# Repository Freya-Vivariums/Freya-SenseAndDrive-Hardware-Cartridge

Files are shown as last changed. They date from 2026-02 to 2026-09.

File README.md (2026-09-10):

Freya banner

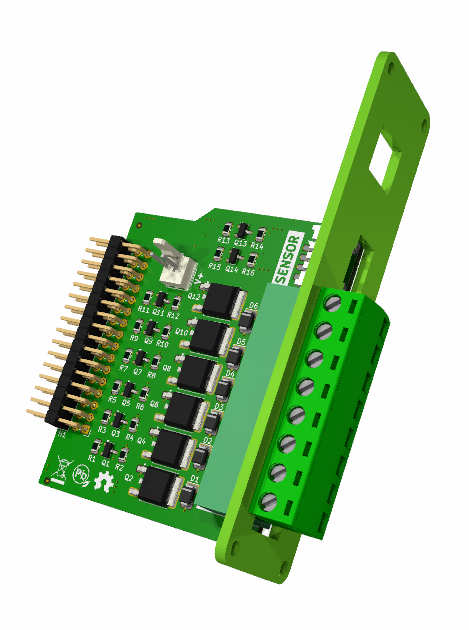
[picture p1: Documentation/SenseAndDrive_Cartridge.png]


The **Sense'n'Drive Hardware Cartridge** equips the [Edgeberry™](https://edgeberry.github.io) based controller with the capability for connecting sensors and driving actuators.

**Features**
- **6 digital outputs** for driving actuators directly or with interposing relays, with internal or external power source.
- **An I²C port** level-shifted to 5V for reliably connecting to the [Freya "Terra" Sensor](https://github.com/Freya-Vivariums/Freya-Terra-Sensor)

<br clear="right"/>

## Usage

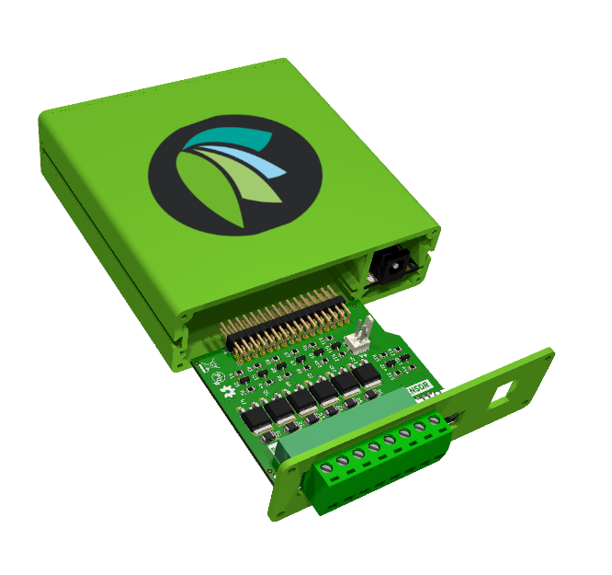
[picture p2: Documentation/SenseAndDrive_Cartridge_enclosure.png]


The Sense'n'Drive Hardware Cartridge is slided in into the expansion slot on the back side of the controller. For using it in your application, install the driver from this repository and include the sdk library in your software.

```js
const { SenseNDriveClient } = require('@freya-vivariums/freya-hardware-cartridge');

const cartridge = new SenseNDriveClient();

cartridge.on('ready', async () => {
  await cartridge.setOutput({ channel: 1, config: { mode: 'switch' }, setpoint: 1 });
  setTimeout(() => cartridge.setOutput({ channel: 1, setpoint: 0 }), 1000);
});
```

<br clear="left"/>

## Hardware

### Sensor Port
The I²C sensor port is **level-shifted to 5V**, and wired to the `HY2.0-4P` connector (informally known as the _Grove connector_) in the following way - making it directly compatible with a wide range of I²C breakout boards from a variety of ecosystems.

|  Pin | Function |
|---|---|
| 1 | SCL |
| 2 | SDA |
| 3 | +5V |
| 4 | GND |

> [!NOTE]
> Before you can use the I²C port `/dev/i2c-1` on Raspberry Pi, it must be enabled by running`sudo raspi-config nonint do_i2c 0`. Or by configuring the overlay manually.

### Digital Outputs
The digital outputs are **sourcing MOSFET** channels rated for up to 1A each, suitable for driving standard industrial actuators such as relays, contactors and solenoids. Output voltage follows the externally applied supply. At 24V DC, the outputs conform to the conventional sourcing digital output arrangement described in IEC 61131-2, so any actuator designed for a standard PLC output can be connected directly. Built-in flyback diodes clamp inductive loads.

> [!IMPORTANT]
> **The digital outputs do not feature internal short-circuit or overcurrent protection**. It is recommended to install a 1A or 1.25A fast-acting fuse on the power supply line.

> [!WARNING]
> The hardware cartridge is designed with a **shared ground for all voltages (non-isolated)**. Always ensure the power supply for the digital outputs and the power supply for the device share a common ground.

The Raspberry Pi GPIO pins are connected to the digital outputs as following:

|Channel |  GPIO  | Software Driver Channel | Comment |
|---|---|---|---|
| D1 | GPIO21 | 1 | |
| D2 | GPIO20 | 2 | |
| D3 | GPIO16 | 3 | |
| D4 | GPIO13 | 4 | |
| D5 | GPIO12 | 5 |Hardware PWM capable* |
| D6 | GPIO18 | 6 |Hardware PWM capable* |

> [!NOTE]
> TODO a note on Hardware PWM on Raspberry Pi

> [!NOTE]
> Controling the digital outputs can be done directly from the commandline using `pinctrl`. For example `pinctrl set 21 op dh` to use GPIO21 as a digital output and set high.

## Software
The **Sense'n'Drive Hardware Cartridge driver** included in the repository is a systemd service (`freya.cartridge.sensendrive`) that is interacted with via a D-Bus API by the client libraries. The service provides methods for controlling the digital outputs in several operating modes.

### D-Bus API
System bus service and interface `freya.cartridge.sensendrive`. Methods are `(s) → s`: a bare JSON request in,
an enveloped JSON response out.

| Method | Request | Result |
|---|---|---|
| `GetOutputs` | `{}` | `{ "outputs": [ ...6...] }` |
| `SetOutput` | one write document | the resulting state |
| `SetOutputs` | `{ "outputs": [ ... ] }` | array of states |

#### Example
`SetOutput` request argument string:
```json
{
  "channel": 2,
  "config": { "mode": "pulse", "frequency_hz": 0.1, "rampRate": 0 },
  "setpoint": 0.321
}
```
Response string:
```json
{ "ok": false, "error": { "code": "EINVAL", "message": "..." } }
```
Or
```json
{ "ok": true, "result": {
    "channel": 2,
    "config": { "mode": "pulse", "frequency_hz": 0.1, "rampRate": 0 },
    "setpoint": 0.321,
    "actual": 0.3 } }
```

Signals: `Ready` at startup, and `OutputChanged` carrying one state document
whenever a channel changes.

## License & Collaboration
**Copyright© 2024-2026 Sanne 'SpuQ' Santens**. The hardware and enclosure are released under the [**CERN OHL-W**](Hardware/LICENSE.txt) license. The driver is released under the [**GNU GPL-3.0**](Software/Driver/LICENSE.txt) license and the sdk libraries under the [**MIT license**](Software/Client/LICENSE.txt) Trademark rules apply to the [Freya™ brand](https://github.com/Freya-Vivariums/.github/blob/main/brand/Freya_Trademark_Rules_and_Guidelines.md).

### Collaboration

If you'd like to contribute to this project, please follow these guidelines:
1. Fork the repository and create your branch from `main`.
2. Make your changes and ensure they adhere to the project's design style and conventions.
3. Test your changes thoroughly.
4. Ensure your commits are descriptive and well-documented.
5. Open a pull request, describing the changes you've made and the problem or feature they address.

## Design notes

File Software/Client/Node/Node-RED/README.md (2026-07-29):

Freya Banner



**[Node-RED](https://nodered.org/)** is a visual programming tool that lets you wire together hardware, APIs, and online services by connecting blocks in a flow-based editor. The **Freya Hardware Cartridge** Node-RED node lets you control the digital outputs of the Freya SenseAndDrive Hardware Cartridge directly from your Node-RED flows over D-Bus.

<br clear="right"/>



## Installation
#### Node-RED flow editor
Navigate to `Settings > Manage Palette`, then in the `Install` tab, search for `@freya-vivariums/freya-hardware-cartridge-node-red-contrib` and click the `Install` button.

#### Manually using NPM
On your device, navigate to the Node-RED folder (on a Freya system, it's at `/opt/Freya/nodered`), and run:
```
npm install @freya-vivariums/freya-hardware-cartridge-node-red-contrib
```

## Node: Digital Output
Controls one of the 6 outputs of the Hardware Cartridge. All Digital Output
nodes automatically share a single connection to the `freya.cartridge.sensendrive`
system D-Bus service, so no separate configuration node is needed. Configure the
physical output channel (1–6) and the mode.

**Input** (`msg.payload`):
- a number `0.0`–`1.0` sets the channel setpoint;
- a boolean maps to a setpoint of `0` / `1`;
- a partial write object `{ config, setpoint }` for full control.

**Output:** a message whose `payload` is the channel state document, emitted
whenever the channel's realized state changes.

**Modes:**
- **Off** (`off`) — output driven low.
- **On/Off** (`switch`) — output high when the realized value is ≥ 0.5.
- **Pulse** (`pwm-slow`) — slow pulse-width modulation, **0.001–1 Hz**. Duty
  cycle equals the setpoint (e.g. 0.1 Hz at 0.3 → 3 s on / 7 s off every 10 s).
- **PWM** (`pwm`) — pulse-width modulation, **1–60 Hz**. The 60 Hz ceiling is
  bounded by the `pinctrl` process-spawn rate (one process per edge, ~1.6 ms
  median / ~7 ms worst on a Raspberry Pi 5); duty accuracy softens toward the
  top of the range. ("PWM fast" is reserved for a future tier.)

  The frequency cap is not the only limit: because each edge costs a process
  spawn, the shortest resolvable on-time is **~5 ms**, and at low duty that
  minimum binds before the frequency does. 60 Hz is fine at 50 % duty (~8 ms
  on-time) but not at 5 % (~0.8 ms). This is not enforced — extreme
  duty/frequency pairs simply degrade gracefully rather than being rejected.

**Frequency** is required for the two PWM modes and rejected out of range; it is
ignored (and hidden) for Off / On/Off. **Ramp rate** is a soft start/stop in
setpoint units per second (`0` = instant); it slides the realized value toward
the setpoint, delaying the On/Off threshold crossing or the PWM duty change.

**Ramping applies in every mode except `off`.** Selecting **Off** is a hard,
immediate stop — it snaps the output low regardless of ramp rate. To fade an
output down instead, keep its mode and set the setpoint to `0`: **`setpoint: 0`
fades, `mode: off` snaps.**

## License & Collaboration
**Copyright© 2025 Sanne 'SpuQ' Santens**. This project is licensed under the **[MIT License](LICENSE.txt)**. The [Rules & Guidelines](https://github.com/Freya-Vivariums/.github/blob/main/brand/Freya_Trademark_Rules_and_Guidelines.md) apply to the usage of the Freya Vivariums™ brand.

### Collaboration
If you'd like to contribute to this project, please follow these guidelines:
1. Fork the repository and create your branch from `main`.
2. Make your changes and ensure they adhere to the project's coding style and conventions.
3. Test your changes thoroughly.
4. Ensure your commits are descriptive and well-documented.
5. Open a pull request, describing the changes you've made and the problem or feature they address.

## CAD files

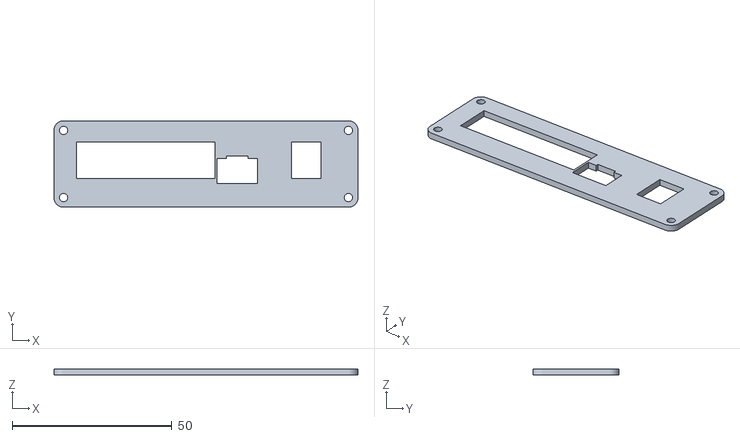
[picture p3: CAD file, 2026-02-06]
Documentation/Edgeberry_SenseAndDrive_faceplate.stl
95.0 x 27.0 x 2.00

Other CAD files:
Enclosure/Edgeberry_SenseAndDrive_faceplate.FCStd

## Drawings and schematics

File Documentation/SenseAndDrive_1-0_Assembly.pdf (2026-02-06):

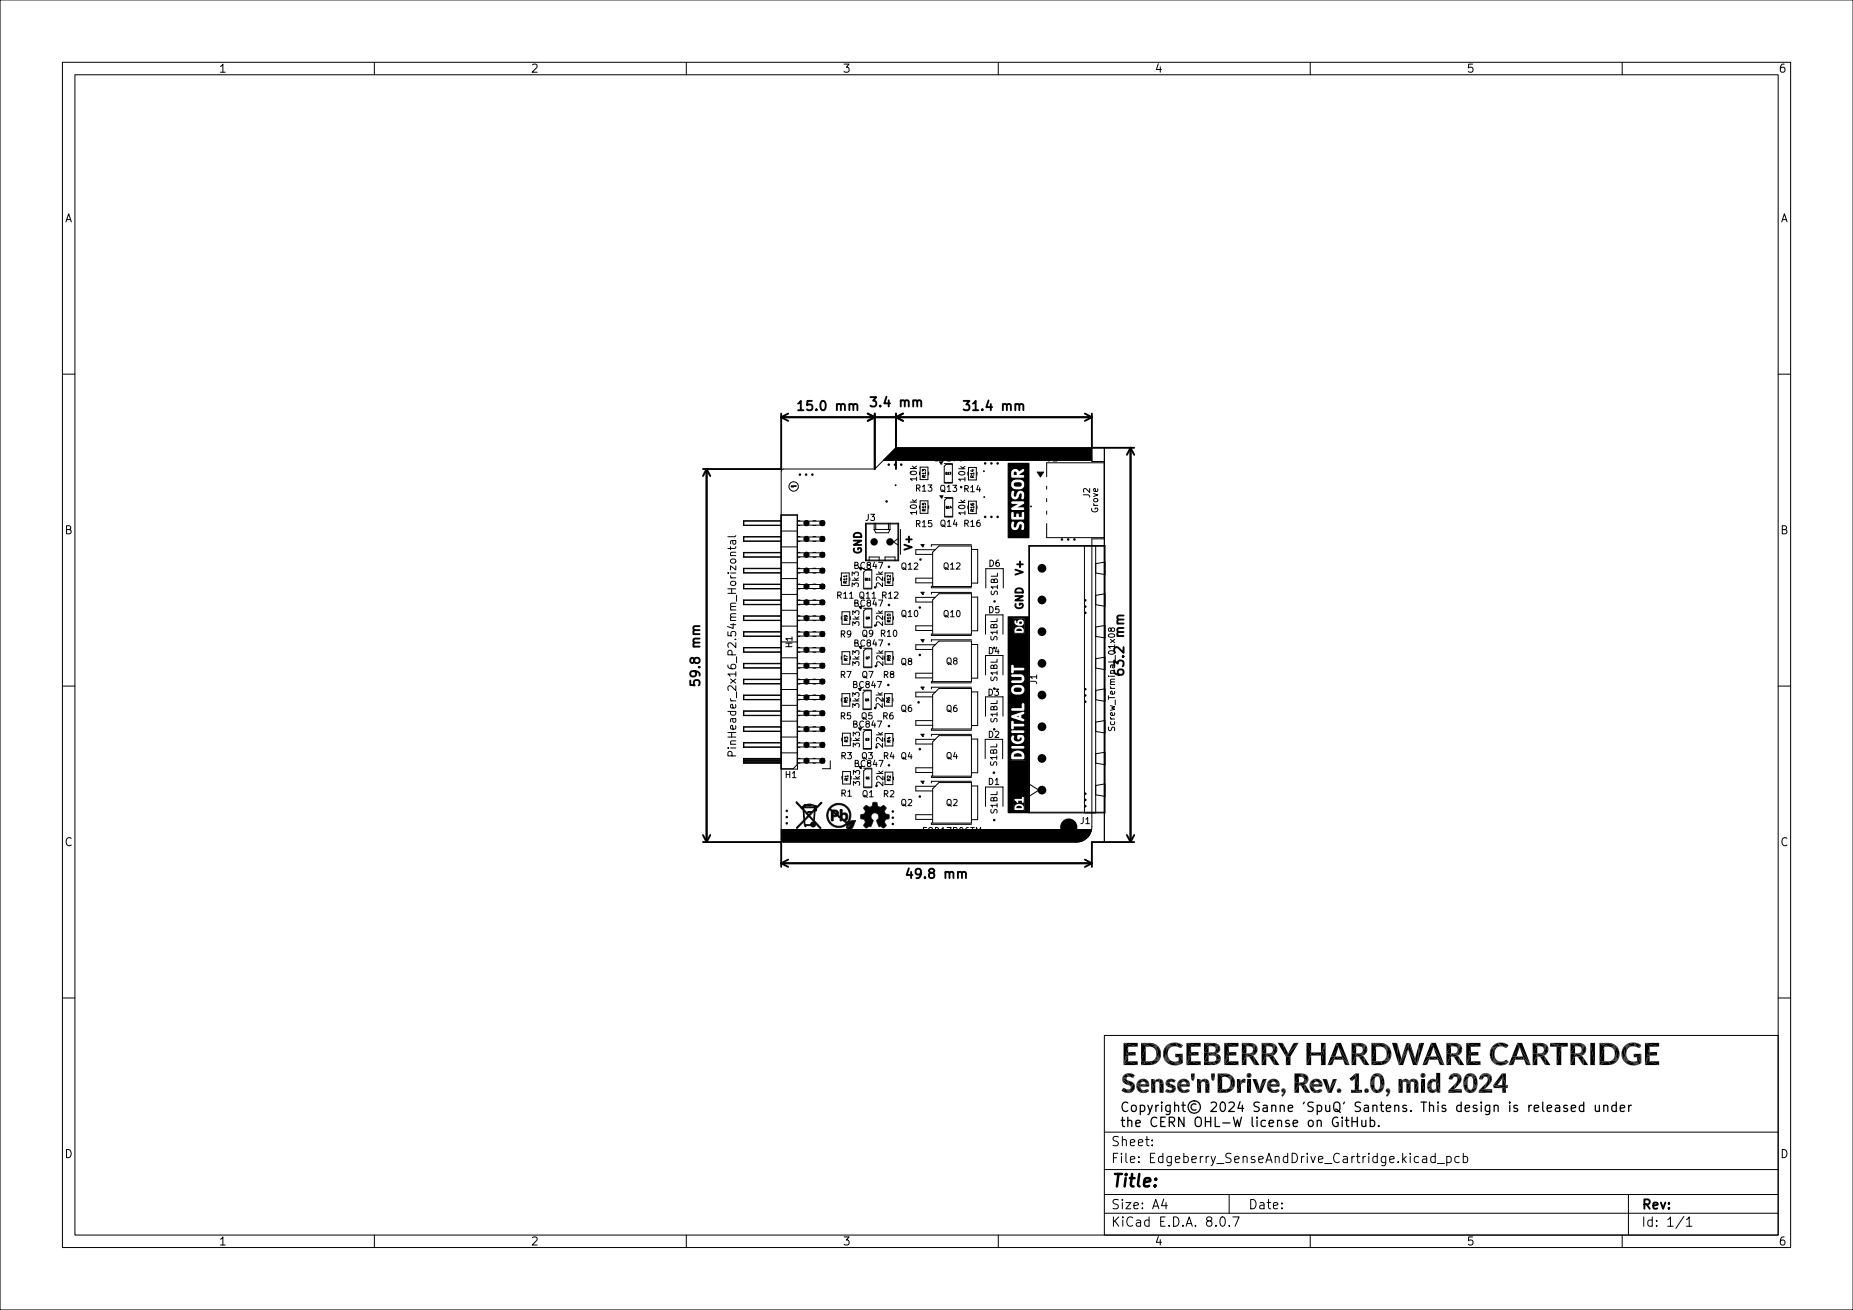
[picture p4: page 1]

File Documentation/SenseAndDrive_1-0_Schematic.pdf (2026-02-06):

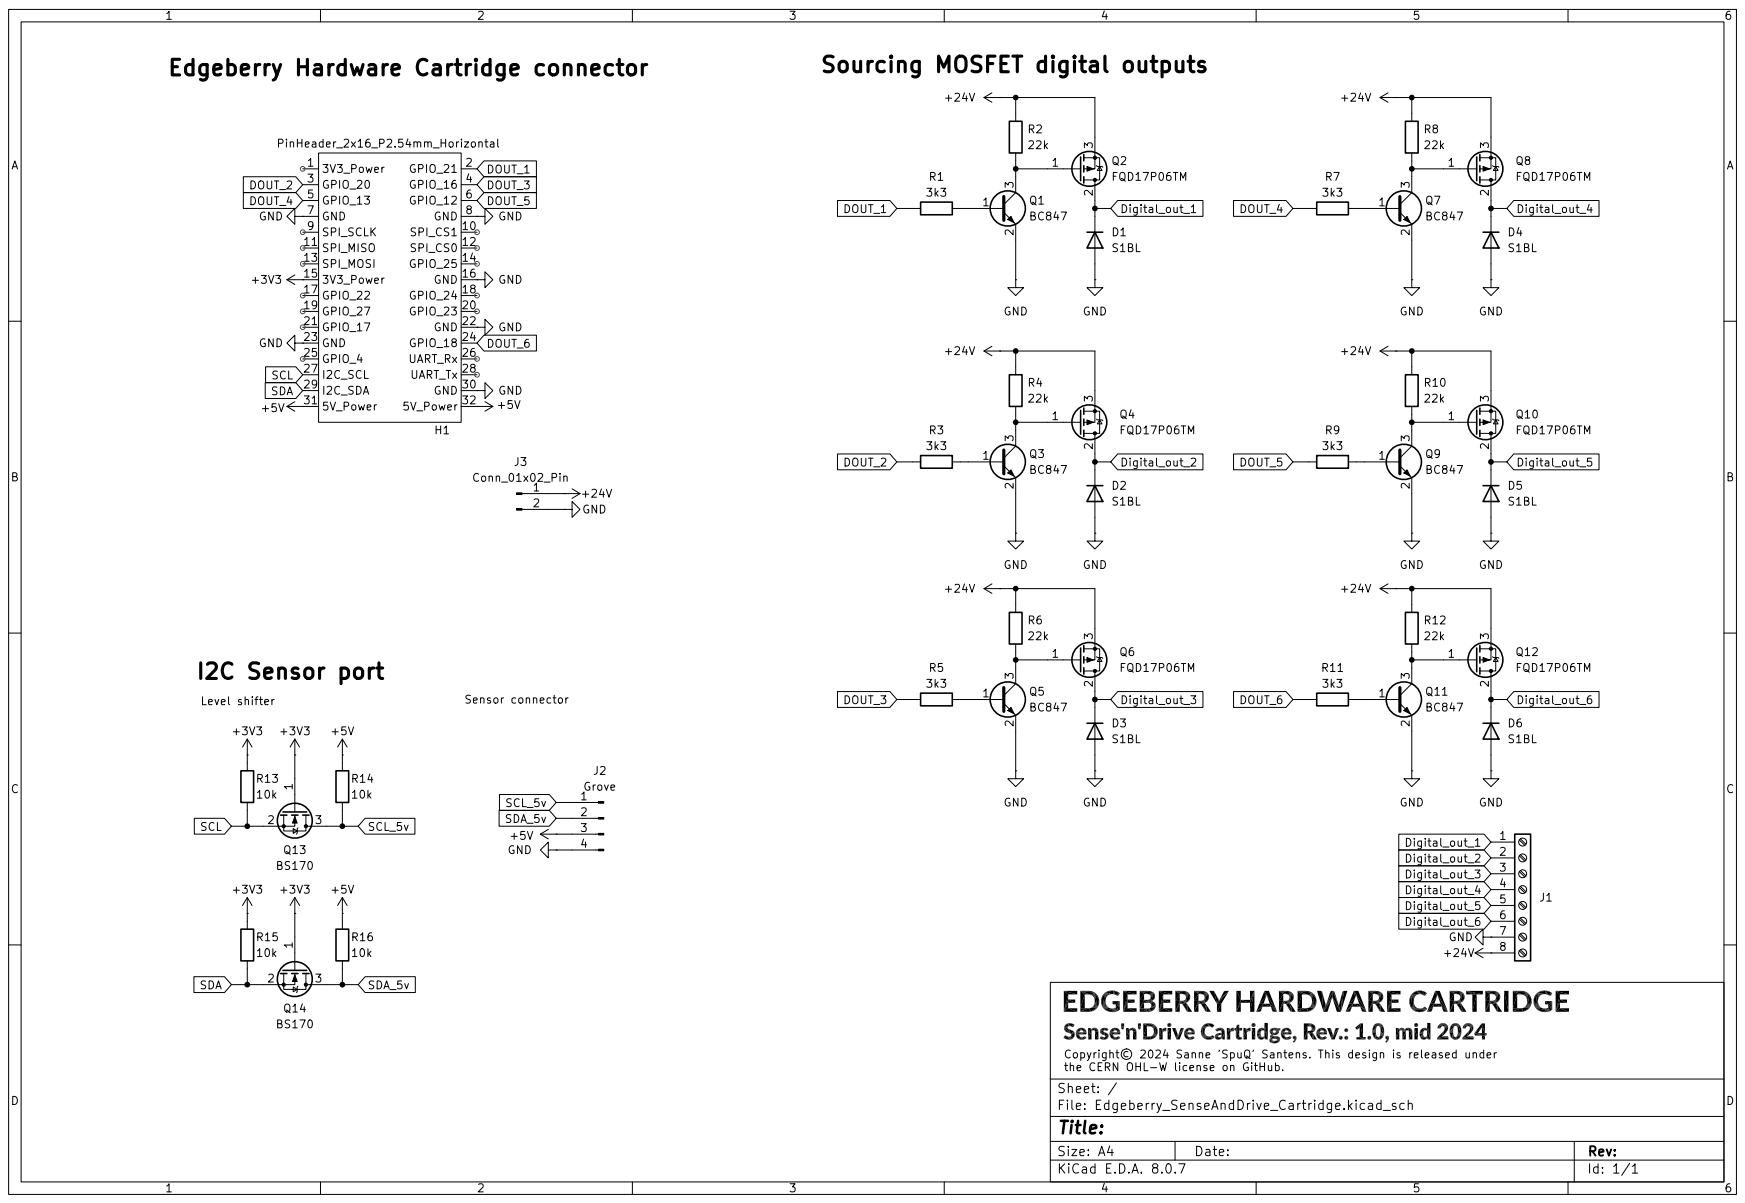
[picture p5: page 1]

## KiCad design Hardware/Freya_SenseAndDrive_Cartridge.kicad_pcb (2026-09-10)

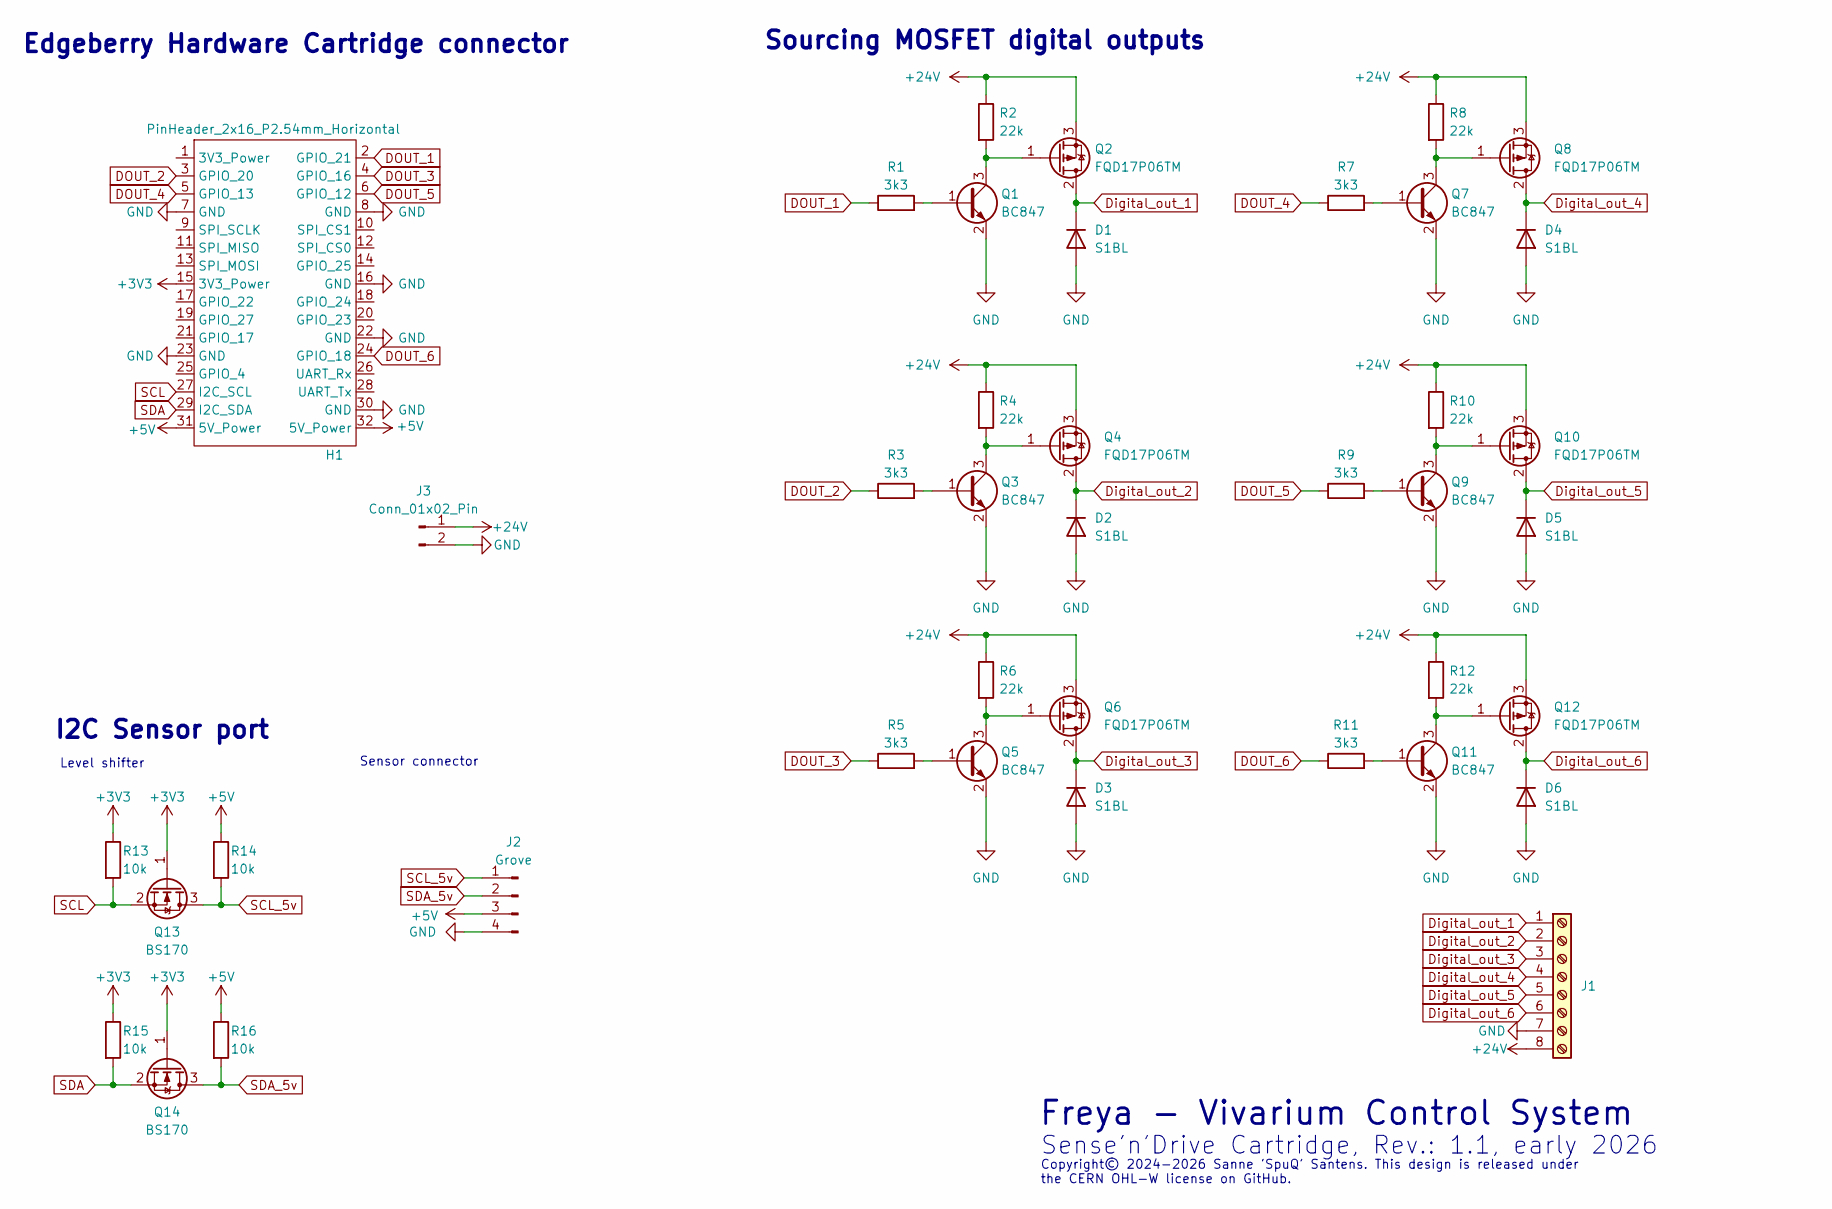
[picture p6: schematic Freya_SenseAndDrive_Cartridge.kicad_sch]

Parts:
D1, D2, D3, D4, D5, D6: S1BL; S1BL_diode
H1: PinHeader_2x16_P2.54mm_Horizontal
J1: Screw_Terminal_01x08; PhoenixContact_MSTBA_2,5_8-G-5,08_1x08_P5.08mm_Horizontal
J2: Grove; Grove_SMD_right_angle
J3: Conn_01x02_Pin; Molex_KK-254_AE-6410-02A_1x02_P2.54mm_Vertical
Q1, Q3, Q5, Q7, Q9, Q11: BC847; SOT-23
Q2, Q4, Q6, Q8, Q10, Q12: FQD17P06TM; TO-252-2
Q13, Q14: BS170; SOT-23
R1, R3, R5, R7, R9, R11: 3k3; R_0805_2012Metric
R2, R4, R6, R8, R10, R12: 22k; R_0805_2012Metric
R13, R14, R15, R16: 10k; R_0805_2012Metric

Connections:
+3V3: H1.15 (3V3_Power), Q13.1 (G), Q14.1 (G), R13.1, R15.1
+5V: H1.31 (5V_Power), H1.32 (5V_Power), J2.3, R14.1, R16.1
+24V: J1.8, J3.1, Q2.3 (S), Q4.3 (S), Q6.3 (S), Q8.3 (S), Q10.3 (S), Q12.3 (S), R2.1, R4.1, R6.1, R8.1, R10.1, R12.1
DOUT_1: H1.2 (GPIO_21), R1.1
DOUT_2: H1.3 (GPIO_20), R3.1
DOUT_3: H1.4 (GPIO_16), R5.1
DOUT_4: H1.5 (GPIO_13), R7.1
DOUT_5: H1.6 (GPIO_12), R9.1
DOUT_6: H1.24 (GPIO_18), R11.1
Digital_out_1: D1.1 (K), J1.1, Q2.2 (D)
Digital_out_2: D2.1 (K), J1.2, Q4.2 (D)
Digital_out_3: D3.1 (K), J1.3, Q6.2 (D)
Digital_out_4: D4.1 (K), J1.4, Q8.2 (D)
Digital_out_5: D5.1 (K), J1.5, Q10.2 (D)
Digital_out_6: D6.1 (K), J1.6, Q12.2 (D)
GND: D1.2 (A), D2.2 (A), D3.2 (A), D4.2 (A), D5.2 (A), D6.2 (A), H1.7 (GND), H1.8 (GND), H1.16 (GND), H1.22 (GND), H1.23 (GND), H1.30 (GND), J1.7, J2.4, J3.2, Q1.2 (E), Q3.2 (E), Q5.2 (E), Q7.2 (E), Q9.2 (E), Q11.2 (E)
unnamed: Q1.1 (B), R1.2
unnamed: Q1.3 (C), Q2.1 (G), R2.2
unnamed: Q3.1 (B), R3.2
unnamed: Q3.3 (C), Q4.1 (G), R4.2
unnamed: Q5.1 (B), R5.2
unnamed: Q5.3 (C), Q6.1 (G), R6.2
unnamed: Q7.1 (B), R7.2
unnamed: Q7.3 (C), Q8.1 (G), R8.2
unnamed: Q9.1 (B), R9.2
unnamed: Q9.3 (C), Q10.1 (G), R10.2
unnamed: Q11.1 (B), R11.2
unnamed: Q11.3 (C), Q12.1 (G), R12.2
SCL: H1.27 (I2C_SCL), Q13.2 (S), R13.2
SCL_5v: J2.1, Q13.3 (D), R14.2
SDA: H1.29 (I2C_SDA), Q14.2 (S), R15.2
SDA_5v: J2.2, Q14.3 (D), R16.2

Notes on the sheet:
Copyright© 2024-2026 Sanne 'SpuQ' Santens. This design is released under the CERN OHL-W license on GitHub.
I2C Sensor port
Freya - Vivarium Control System
Sense'n'Drive Cartridge, Rev.: 1.1, early 2026
Sourcing MOSFET digital outputs
Sensor connector
Level shifter
Edgeberry Hardware Cartridge connector

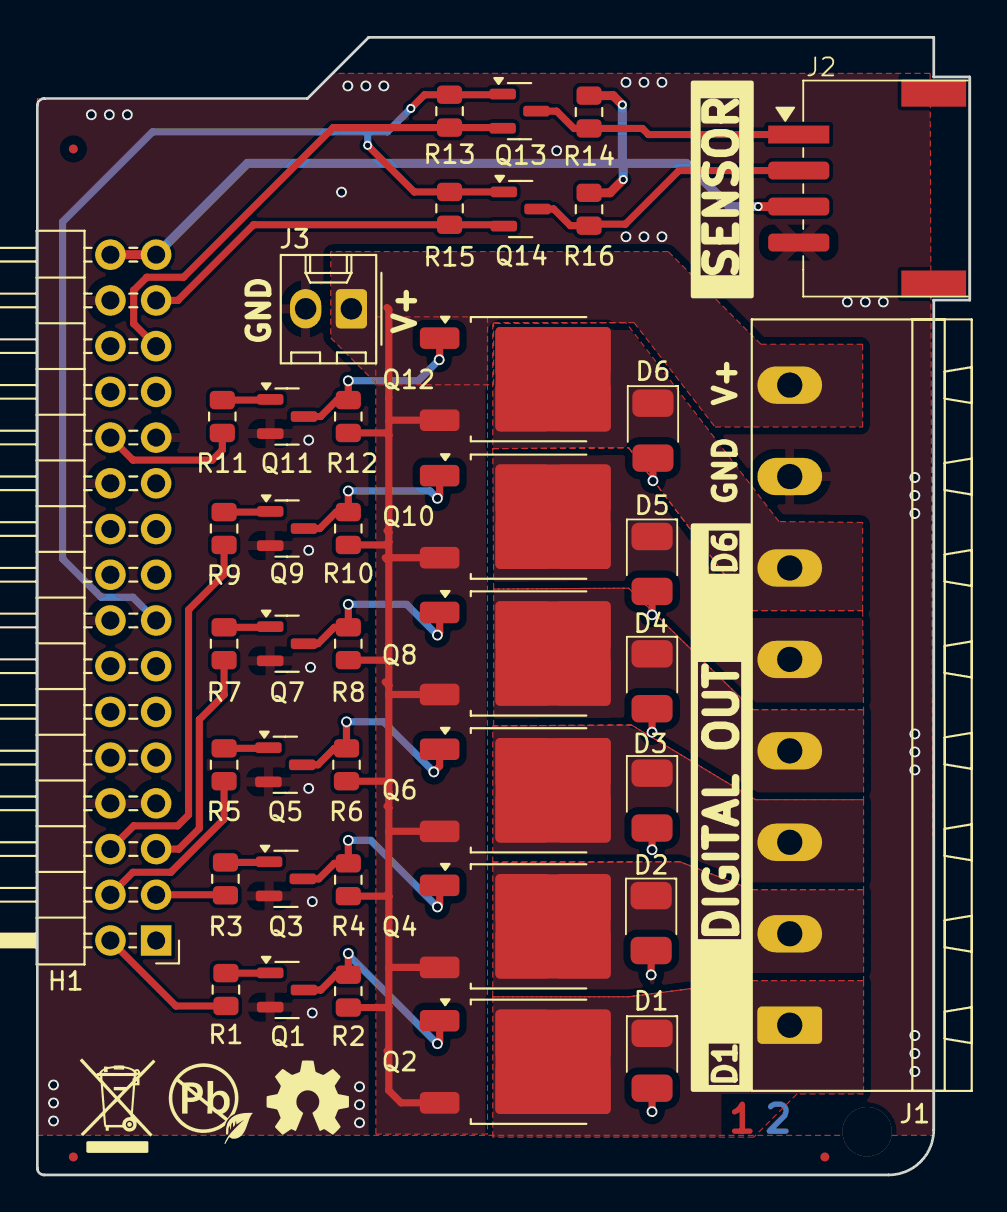
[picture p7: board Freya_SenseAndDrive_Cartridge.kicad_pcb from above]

Board: 2 copper layers, 51.8 x 63.2 mm, 40 parts (0 on the bottom side), 32 nets.

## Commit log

2026-02-06 Project's structure adaptation
    [Edgeberry_SenseAndDrive_Cartridge.kicad_pcb, Edgeberry_SenseAndDrive_Cartridge.kicad_sch, Edgeberry_SenseAndDrive_faceplate.FCStd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]
2026-02-06 Hardware: naming in project
    [Freya_SenseAndDrive_Cartridge.kicad_pcb, Freya_SenseAndDrive_Cartridge.kicad_sch]
2026-02-09 Repo organization: software driver + client
2026-04-16 Hardware: Enclosure update
    [Edgeberry_SenseAndDrive_faceplate.FCStd, Freya_SenseAndDrive_Cartridge.kicad_pcb]
2026-04-20 Documentation: cartridge usage
    [Freya_SenseAndDrive_Cartridge.kicad_pcb]
2026-07-27 Driver API overhaul + client Node Library and Node-RED implementations
2026-09-09 ReadMe: no overcurrent or short-circuit protection internal
2026-09-09 ReadMe: Sensor port
2026-09-10 ReadMe: licenses update + PCB color
    [Freya_SenseAndDrive_Cartridge.kicad_pcb]
2026-09-10 ReadMe: PWM pin documentation

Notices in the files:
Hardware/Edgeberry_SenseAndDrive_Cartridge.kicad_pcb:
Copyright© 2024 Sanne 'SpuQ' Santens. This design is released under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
